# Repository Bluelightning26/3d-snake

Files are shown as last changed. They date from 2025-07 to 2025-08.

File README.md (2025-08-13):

# Spinny Snake 3d
**Made at Undercity!**



In this custom rendition of the classic game of snake we overhauled the experience. With features including a score counter, high score display, speaker, sound effect buzzer, calibrated joystick, and most importantly a custom implementation of a cubic matrix display that recognizes directionality among much more, there is plenty of fun to be had :) The whole console also rotates using a stepper motor when the snake slithers across displays so the user can always see where the snake is!

## Wiring (basics)
Wiring diagram

note: the contents of the 3v3, 5v and ground power rails are not listed here

## How to Play
The console utilize a joystick for controls. Moving it around helps orientate your snake! You'll die if you either hit the ground or if you back into yourself. You get a point if you slither into an apple. 

Depending on the version of game played, if you eat a mystery apple (orange and purple) you will either get a speed boost or a slowness effect.

# BOM
[BOM.md](./BOM.md)

## Progress Images














## Youtube Video Demo
[https://www.youtube.com/shorts/mjqKc-JOmLc](https://www.youtube.com/shorts/mjqKc-JOmLc)

## More info on Undercity
[https://undercity.hackclub.com/](https://undercity.hackclub.com/)

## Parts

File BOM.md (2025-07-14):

## BOM
| Name | Part No. | Quantity | Other |
| :-: | :-: | :-: | :-: |
| Orpheus Pico | OR2040 | 2 |  |
| 8x8 Neopixel Matrix | WS2812B-64 | 5 | https://www.digikey.com/en/products/detail/adafruit-industries-llc/1487/5154669 |
| Solderless Breadboard Jumper Wires (Some Stripped, and ironically soldered) | - |  |  |
| Breadboard | - |  |  |
| 7 Segment Display | 3642BS-1 | 2 |  |
| Joystick | HW-504 |  |  |
| Speaker 8Ω 2W | (Generic) | 1 |  |
| Slide Potentiometer | HW-233 |  |  |
| Switch SW | Generic Button |  |  |
| Cherry MX Switch |  | 2 |  |
| Keycaps |  | 2 |  |
| Stepper Motor | 17HE15-1504S | 1 |  |
| Stepper Motor Driver Carrier | DRV8825 | 1 |  |
| 1.8# SPI TFT Module | MSP1803 |  |  |
| Amplifier | MAX98357A | 1 |  |
| Ultra Alkaline PICELL 9v Battery | 6LR61 | 2 |  |

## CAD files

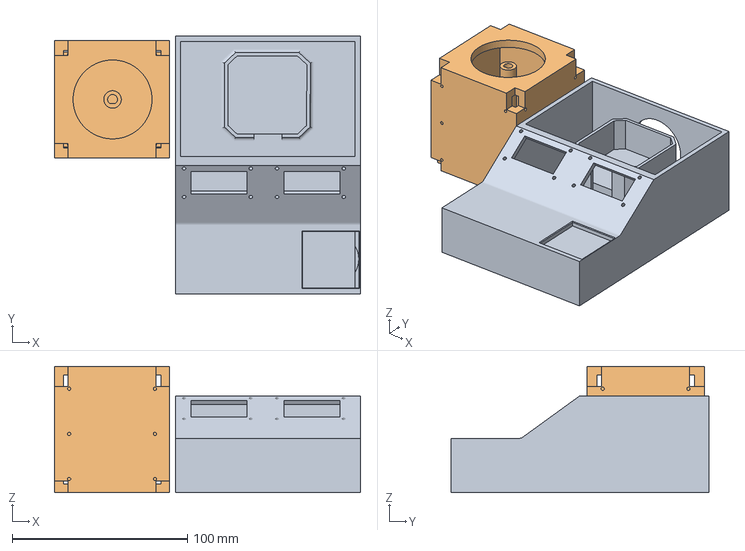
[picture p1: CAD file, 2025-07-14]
3d Prints/Full Case.3mf
174.5 x 147.0 x 72.0 mm
LED Case.stl

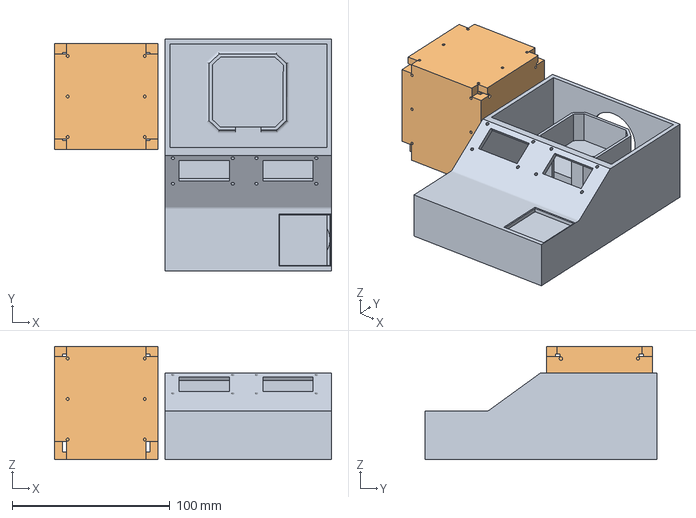
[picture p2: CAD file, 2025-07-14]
3d Prints/BaseCase.3mf
175.7 x 147.0 x 72.0 mm
LED Case.stl

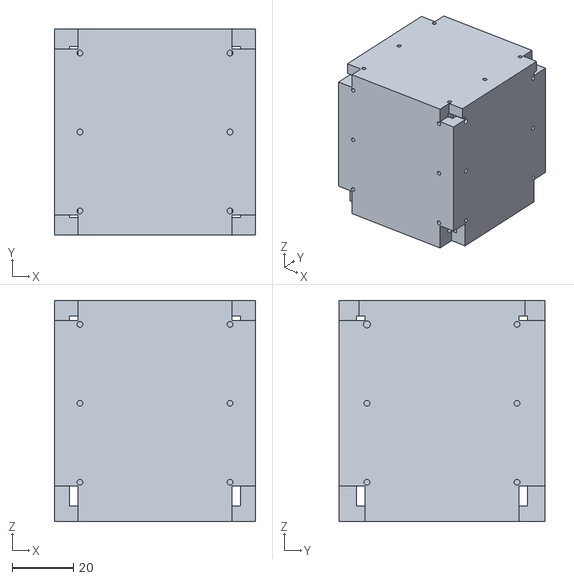
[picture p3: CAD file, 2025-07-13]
3d Prints/LED Case.stl
65.6 x 67.0 x 72.0

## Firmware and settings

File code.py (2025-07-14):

import board
import neopixel
import time
import random
import analogio
import pwmio
import tm1637
import digitalio
import digitalio
import time

# === Motor Control Setup ===
# GPIO pin assignments for DRV8825
DIR_PIN = board.GP2    # Direction control
STEP_PIN = board.GP8   # Step control
SLP_PIN = board.GP4    # Sleep control (active HIGH)
RST_PIN = board.GP5    # Reset control (active HIGH)
FLT_PIN = board.GP6    # Fault pin (optional, active LOW when fault)
EN_PIN = board.GP7     # Enable control (active LOW)

# Initialize motor control pins
dir_pin = digitalio.DigitalInOut(DIR_PIN)
dir_pin.direction = digitalio.Direction.OUTPUT

step_pin = digitalio.DigitalInOut(STEP_PIN)
step_pin.direction = digitalio.Direction.OUTPUT

sleep_pin = digitalio.DigitalInOut(SLP_PIN)
sleep_pin.direction = digitalio.Direction.OUTPUT

reset_pin = digitalio.DigitalInOut(RST_PIN)
reset_pin.direction = digitalio.Direction.OUTPUT

enable_pin = digitalio.DigitalInOut(EN_PIN)
enable_pin.direction = digitalio.Direction.OUTPUT

# Optional fault pin (input with pull-up)
fault_pin = digitalio.DigitalInOut(FLT_PIN)
fault_pin.direction = digitalio.Direction.INPUT
fault_pin.pull = digitalio.Pull.UP

# Motor configuration
STEPS_PER_90_DEGREES = 50  # 90° rotation
MAX_ROTATION_STEPS = 200   # 360° limit (4 * 50 steps)

# Motor state tracking
current_rotation_steps = 0  # Track total rotation from start position
target_panel = 1  # Current target panel


def init_motor():
    """Initialize the DRV8825 driver"""
    print("Initializing DRV8825 driver...")
    
    # Enable driver (active LOW)
    enable_pin.value = False
    
    # Enable driver (wake up from sleep)
    sleep_pin.value = True
    
    # Release reset (active high)
    reset_pin.value = True
    
    # Set initial direction
    dir_pin.value = True  # True = CW, False = CCW
    step_pin.value = False
    
    time.sleep(0.1)  # Allow driver to initialize
    print("Driver initialized!")

def check_motor_fault():
    """Check if there's a fault condition"""
    return not fault_pin.value  # Fault is active LOW


def step_motor(steps=50, direction=True, delay=0.001):
    """
    Step the motor
    steps: number of steps to take
    direction: True for clockwise, False for counter-clockwise
    delay: delay between steps in seconds
    """
    if check_fault():
        print("ERROR: Fault detected! Check wiring and power supply.")
        return
    
    dir_pin.value = direction
    print(f"Stepping {steps} steps {'CW' if direction else 'CCW'}")
    
    for i in range(steps):
        step_pin.value = True
        time.sleep(delay)
        step_pin.value = False
        time.sleep(delay)
        
        # Check fault every 100 steps
        if i % 100 == 0 and check_fault():
            print(f"Fault detected at step {i}!")
            break

def move_motor(clockwise=True, delay=0.001):
    """
    Move motor exactly 90 degrees (50 steps)
    Based on the step_motor function from tester code
    Returns True if successful, False if failed
    """
    global current_rotation_steps
    
    if check_motor_fault():
        print("ERROR: Fault detected! Check wiring and power supply.")
        return False
    
    # Set direction
    dir_pin.value = clockwise
    print(f"Stepping {STEPS_PER_90_DEGREES} steps {'CW' if clockwise else 'CCW'}")
    
    # Step the motor using the same pattern as tester code
    for i in range(STEPS_PER_90_DEGREES):
        step_pin.value = True
        time.sleep(delay)
        step_pin.value = False
        time.sleep(delay)
        
        # Check fault every 10 steps (more frequent than tester's 100)
        if i % 10 == 0 and check_motor_fault():
            print(f"Fault detected at step {i}!")
            return False
    
    # Update current position
    if clockwise:
        current_rotation_steps += STEPS_PER_90_DEGREES
    else:
        current_rotation_steps -= STEPS_PER_90_DEGREES
    
    print(f"Motor moved successfully. Current position: {current_rotation_steps} steps")
    return True

def calculate_rotation_to_panel(current_panel, target_panel):
    """
    Calculate how many 90° rotations needed to get from current to target panel
    Returns (number_of_rotations, clockwise_direction)
    Positive rotations = clockwise, negative = counter-clockwise
    """
    # Panel arrangement: 1(front) -> 2(right) -> 3(back) -> 4(left) -> 1...
    diff = target_panel - current_panel
    
    # Normalize to shortest path
    if diff > 2:
        diff -= 4  # Go CCW instead
    elif diff < -2:
        diff += 4  # Go CW instead
    
    return diff  # Positive = CW, negative = CCW

def rotate_to_panel(target_panel_num):
    """
    Rotate cube to show specified panel on the left
    Handles 360° limit by choosing alternative direction if needed
    """
    global target_panel, current_rotation_steps
    
    if target_panel_num == target_panel:
        return True  # Already at target
    
    # Calculate ideal rotation
    rotations_needed = calculate_rotation_to_panel(target_panel, target_panel_num)
    
    # Check if ideal rotation would exceed limits
    projected_steps = current_rotation_steps + (rotations_needed * STEPS_PER_90_DEGREES)
    
    if abs(projected_steps) > MAX_ROTATION_STEPS:
        # Try opposite direction (non-ideal but within limits)
        print(f"Ideal rotation would exceed 360° limit, trying opposite direction")
        rotations_needed = -rotations_needed
        if rotations_needed > 0:
            rotations_needed = 4 - rotations_needed  # Go the long way around
        else:
            rotations_needed = -4 - rotations_needed  # Go the long way around
        
        projected_steps = current_rotation_steps + (rotations_needed * STEPS_PER_90_DEGREES)
        
        if abs(projected_steps) > MAX_ROTATION_STEPS:
            print(f"Cannot rotate to panel {target_panel_num}: would exceed limits in both directions")
            return False
    
    # Perform the rotation
    clockwise = rotations_needed > 0
    abs_rotations = abs(rotations_needed)
    
    print(f"Rotating {abs_rotations} steps to reach panel {target_panel_num}")
    
    for i in range(abs_rotations):
        if not move_motor(clockwise):
            print(f"Motor movement failed at rotation {i+1}")
            return False
        time.sleep(0.05)  # Small delay between 90° rotations
    
    target_panel = target_panel_num
    print(f"Successfully rotated to panel {target_panel}")
    return True
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

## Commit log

2025-07-13 first part of the case
    [LED Case.stl]
2025-07-13 case change
    [LED Case.stl]
2025-07-13 buzz buzz
    😴❌
2025-07-13 pin pin
2025-07-14 bottom case
    [BaseCase.3mf]
2025-07-14 full case
    [BaseCase.3mf, Full Case.3mf]
2025-08-06 add current poster!
    not final but looks great
